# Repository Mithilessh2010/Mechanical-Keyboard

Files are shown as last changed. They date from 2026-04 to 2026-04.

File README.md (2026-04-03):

# Transparent Keyboard

This is a custom mechanical keyboard with a fully clear acrylic case and transparent keycaps.  
The goal of this project was to build a simple keyboard that shows all of the internal parts, lighting, and wiring.





---

## About

This keyboard is designed to be easy to see through and easy to understand.  
Every major part is visible, including the PCB, LEDs, switches, and wiring.  
It uses QMK firmware and a Teensy microcontroller.

---

## Firmware

This keyboard uses QMK firmware.

**Flashing steps**

1. Download QMK Toolbox.
2. Plug the Teensy 2.0 into your computer.
3. Press the boot button on the Teensy.
4. Flash the provided `.hex` firmware file using QMK Toolbox.

---

## Bill of Materials (BOM)

| Item | Price | Quantity | Purpose | Link |
|---|---|---|---|---|
| KTT Kang White V3 Switches | $24.89 | 1 pack (90 pcs) | Mechanical key switches | https://www.aliexpress.us/item/3256807301426125.html |
| WS2812B LED Strip 5V (2m) | $5.16 | 1 strip | RGB backlighting | https://www.aliexpress.us/item/3256804103077154.html |
| Teensy 2.0 | $9.18 | 1 | Microcontroller | https://www.aliexpress.us/item/3256803067426595.html |
| USB Adapter 20cm V8F-V3ST | $2.24 | 1 | Internal USB cable | https://www.aliexpress.us/item/3256805661411472.html |
| Transparent Keycaps | $18.82 | 1 set | Keycaps | https://www.aliexpress.us/item/3256809158263730.html |
| 1/8 in Acrylic Sheet | $15.00 | 1 sheet | Case and plates | Makerspace |
| M2 Screws 4mm | $2.24 | 1 pack | Mounting hardware | https://www.aliexpress.us/item/3256806812715286.html |
| M3 Screws | $0.00 | Owned | Case assembly | Already owned |
| Custom PCBs (JLCPCB) | $33.74 | 5 boards | Keyboard PCB | JLCPCB |
| Keyboard Diodes | $2.38 | 2 packs | Switch matrix diodes | https://www.aliexpress.us/item/3256806058794623.html |
| Gateron V2 Stabilizers | $10.00 | 1 kit | Stabilizers for larger keys | https://mechanicalkeyboards.com/products/gateron-v2-stabilizers-plate-mount-clip-in-tkl-kit |

**Estimated total (before tax and shipping): $121.32**

---

## Notes

This project was made for learning and for fun.  
Feel free to reuse or modify anything in this repository for your own keyboard builds.

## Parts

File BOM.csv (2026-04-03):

Item | Price (USD) | Quantity | Use | Link
KTT Kang White V3 Switches | 24.89 | 1 pack (90 pcs) | Mechanical key switches | https://www.aliexpress.us/item/3256807301426125.html
WS2812B LED Strip 5V 2m 30 LEDs | 5.16 | 1 strip (2m) | Keyboard backlighting | https://www.aliexpress.us/item/3256804103077154.html
Teensy 2.0 Microcontroller | 9.18 | 1 | Keyboard MCU | https://www.aliexpress.us/item/3256803067426595.html
USB Adapter 20cm V8F-V3ST | 2.24 | 1 | USB connection adapter | https://www.aliexpress.us/item/3256805661411472.html
Transparent Keycaps Set | 18.82 | 1 set | Keycaps | https://www.aliexpress.us/item/3256809158263730.html
1/8 in Acrylic Sheet | 15.00 | 1 sheet | Keyboard plate and backplate | Makerspace purchase
M2 Screws 4mm | 2.24 | 1 pack | Mount PCB to case | https://www.aliexpress.us/item/3256806812715286.html
M3 Screws | 0.00 | Owned | General assembly | Already owned
Custom PCBs (JLCPCB) | 33.74 | 5 boards | Keyboard PCB fabrication | JLCPCB
Keyboard Diodes | 2.38 | 2 packs | Switch matrix diodes | https://www.aliexpress.us/item/3256806058794623.html
Gateron V2 Stabilizers Kit | 10.00 | 1 kit | Stabilize larger keys | https://mechanicalkeyboards.com/products/gateron-v2-stabilizers-plate-mount-clip-in-tkl-kit
TOTAL (No tax/shipping) | 123.65
FINAL TOTAL | 121.32

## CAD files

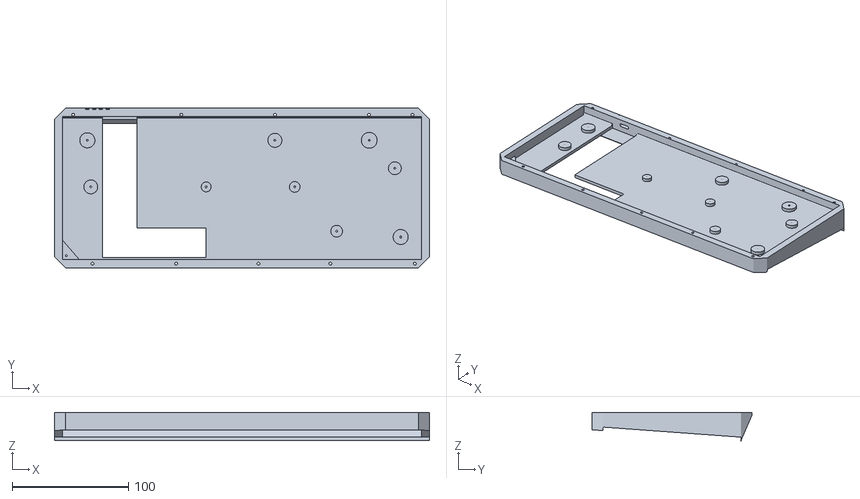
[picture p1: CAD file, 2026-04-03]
Cad files/Bottom whole.stl
321.9 x 137.2 x 24.3

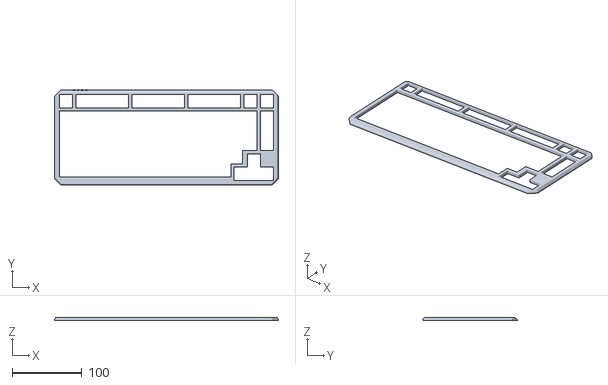
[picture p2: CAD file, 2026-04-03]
Cad files/top whole.stl
321.9 x 137.2 x 4.90

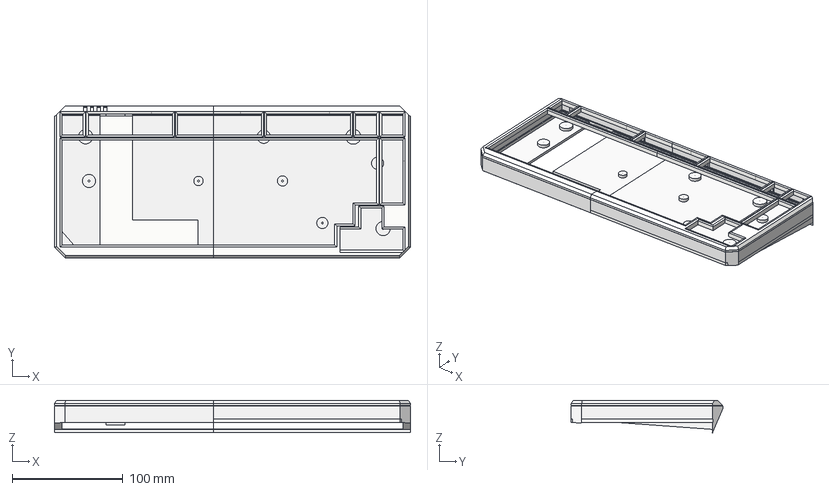
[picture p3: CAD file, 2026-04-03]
Cad files/Transparent Keyboard.step
321.9 x 137.2 x 29.3 mm

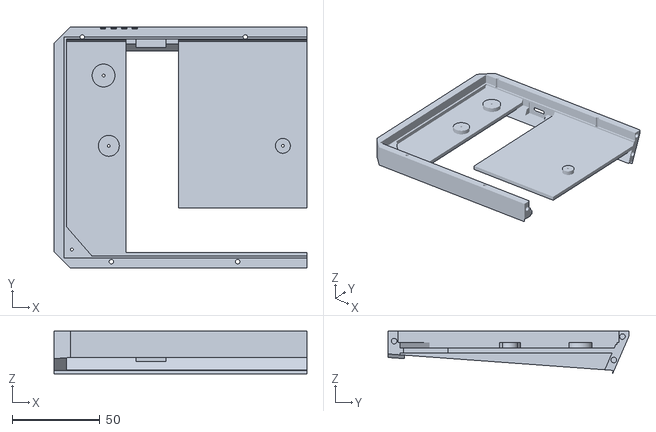
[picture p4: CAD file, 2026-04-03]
Cad files/Left bottom.stl
143.9 x 137.2 x 24.3

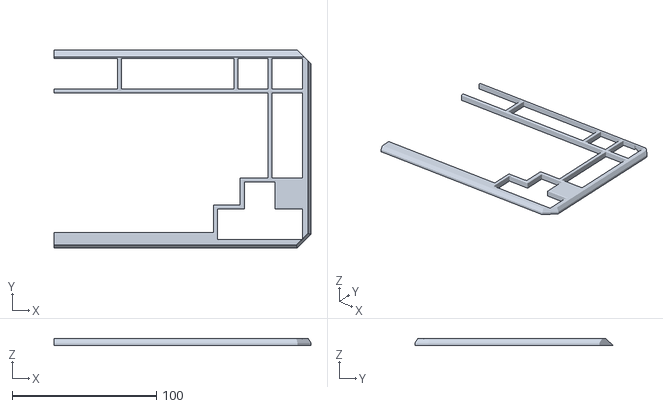
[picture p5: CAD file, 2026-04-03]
Cad files/Right top.stl
178.0 x 137.2 x 4.90

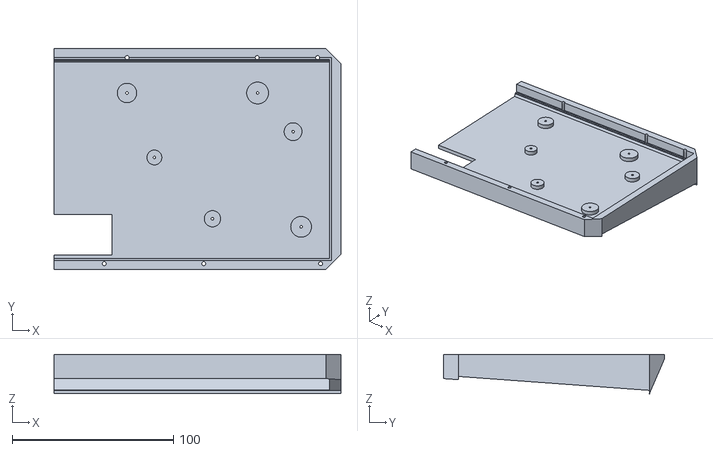
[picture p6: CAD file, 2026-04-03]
Cad files/Right bottom.stl
178.0 x 137.2 x 24.3

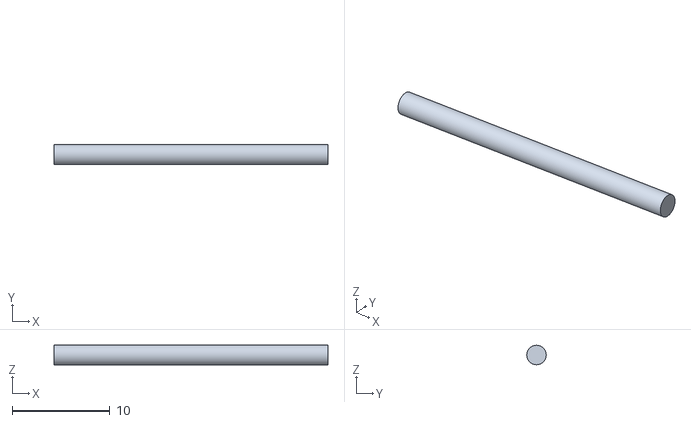
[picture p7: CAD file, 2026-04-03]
Cad files/pin.stl
28.0 x 2.00 x 2.00

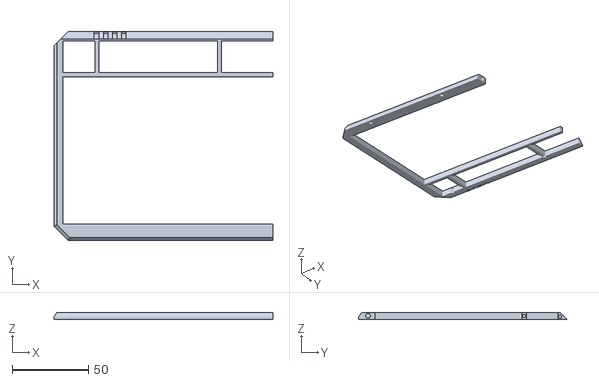
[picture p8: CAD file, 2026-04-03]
Cad files/Left top.stl
143.9 x 137.2 x 4.90

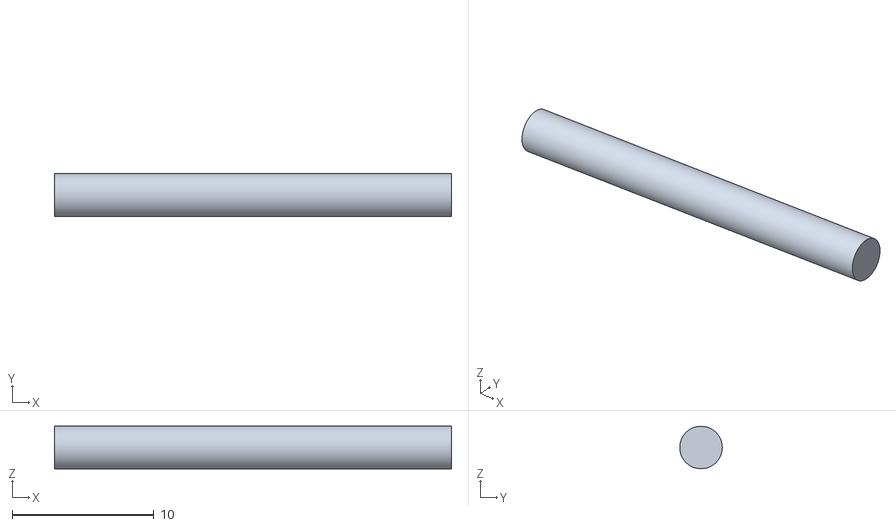
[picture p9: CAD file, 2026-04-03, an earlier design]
Cad files/pin (2).stl
28.0 x 3.00 x 3.00

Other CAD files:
Cad files/main base.stl
Cad files/Top Plate.stl
Cad files/pin (3).stl
Cad files/pin (4).stl
Cad files/pin (5).stl
Cad files/pin (1).stl

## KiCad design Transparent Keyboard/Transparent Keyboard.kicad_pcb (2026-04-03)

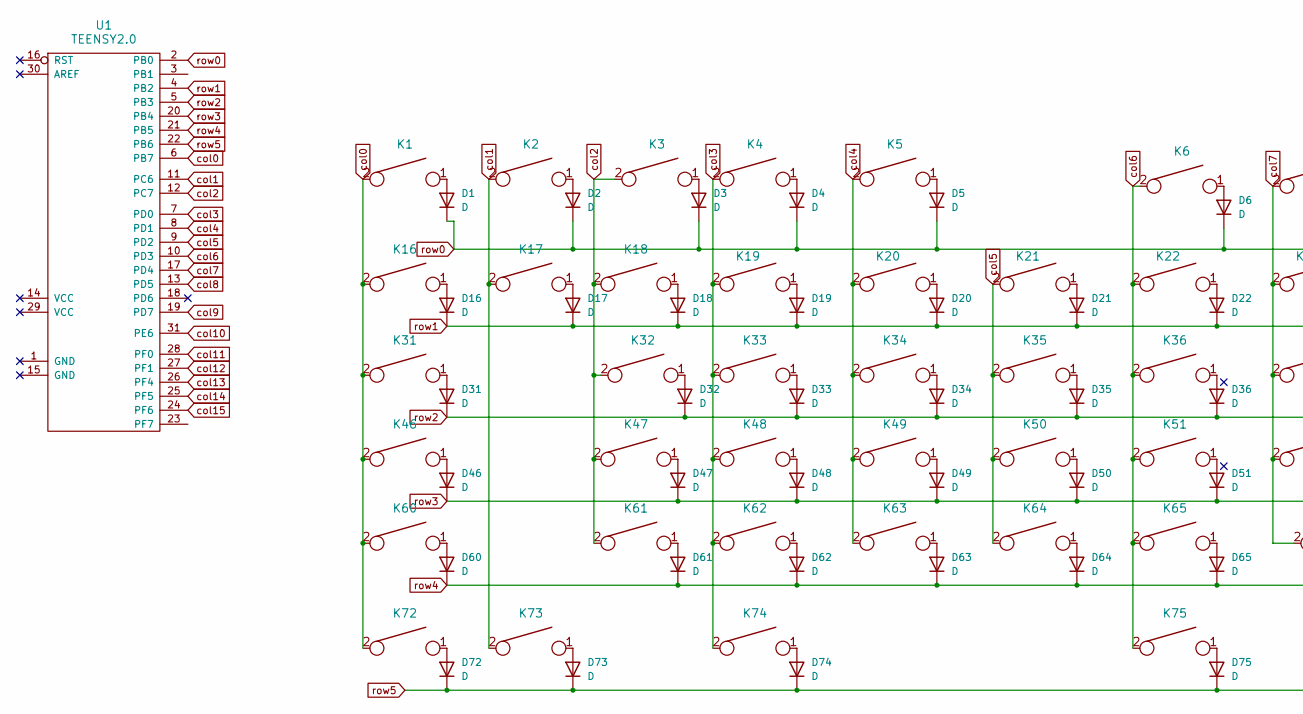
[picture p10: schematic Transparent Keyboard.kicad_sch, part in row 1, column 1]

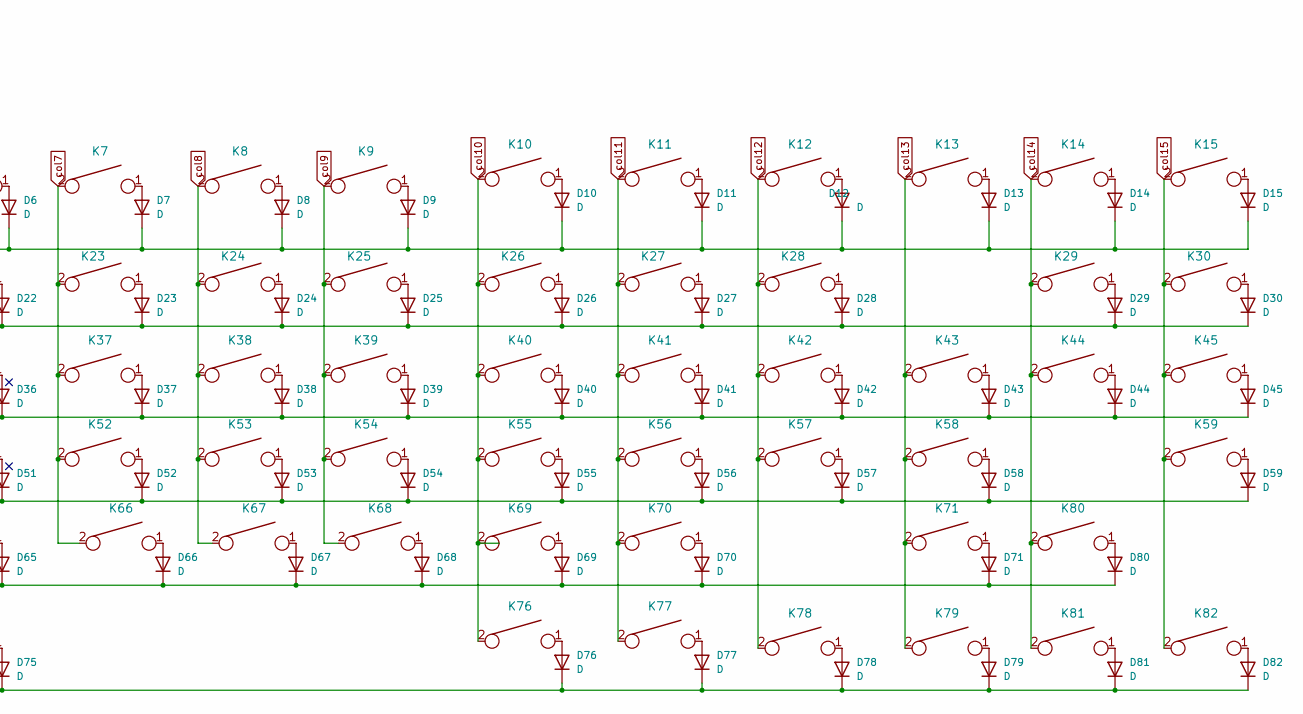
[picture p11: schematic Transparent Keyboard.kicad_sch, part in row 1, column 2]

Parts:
D1, D2, D3, D4, D5, D6, D7, D8, D9, D10, D11, D12, D13, D14, D15, D16, D17, D18, D19, D20, D21, D22, D23, D24, D25, D26, D27, D28, D29, D30, D31, D32, D33, D34, D35, D36, D37, D38, D39, D40, D41, D42, D43, D44, D45, D46, D47, D48, D49, D50, D51, D52, D53, D54, D55, D56, D57, D58, D59, D60, D61, D62, D63, D64, D65, D66, D67, D68, D69, D70, D71, D72, D73, D74, D75, D76, D77, D78, D79, D80, D81, D82: D; D_SOD123_axial
K1, K2, K3, K4, K5, K6, K7, K8, K9, K10, K11, K12, K13, K14, K15, K16, K17, K18, K19, K20, K21, K22, K23, K24, K25, K26, K27, K28, K30, K32, K33, K34, K35, K36, K37, K38, K39, K40, K41, K42, K43, K45, K47, K48, K49, K50, K51, K52, K53, K54, K55, K56, K57, K59, K61, K62, K63, K64, K65, K66, K67, K68, K69, K70, K71, K72, K73, K74, K75, K76, K77, K78, K79, K80, K81, K82: KEYSW; Mx_Alps_100
K29: KEYSW; Mx_Alps_200
K31, K44: KEYSW; Mx_Alps_150
K46: KEYSW; Mx_Alps_175
K58, K60: KEYSW; Mx_Alps_225
U1: TEENSY2.0; Teensy_20

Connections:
unnamed: D1.2 (A), K1.1
unnamed: D2.2 (A), K2.1
unnamed: D3.2 (A), K3.1
unnamed: D4.2 (A), K4.1
unnamed: D5.2 (A), K5.1
unnamed: D6.2 (A), K6.1
unnamed: D7.2 (A), K7.1
unnamed: D8.2 (A), K8.1
unnamed: D9.2 (A), K9.1
unnamed: D10.2 (A), K10.1
unnamed: D11.2 (A), K11.1
unnamed: D12.2 (A), K12.1
unnamed: D13.2 (A), K13.1
unnamed: D14.2 (A), K14.1
unnamed: D15.2 (A), K15.1
unnamed: D16.2 (A), K16.1
unnamed: D17.2 (A), K17.1
unnamed: D18.2 (A), K18.1
unnamed: D19.2 (A), K19.1
unnamed: D20.2 (A), K20.1
unnamed: D21.2 (A), K21.1
unnamed: D22.2 (A), K22.1
unnamed: D23.2 (A), K23.1
unnamed: D24.2 (A), K24.1
unnamed: D25.2 (A), K25.1
unnamed: D26.2 (A), K26.1
unnamed: D27.2 (A), K27.1
unnamed: D28.2 (A), K28.1
unnamed: D29.2 (A), K29.1
unnamed: D30.2 (A), K30.1
unnamed: D31.2 (A), K31.1
unnamed: D32.2 (A), K32.1
unnamed: D33.2 (A), K33.1
unnamed: D34.2 (A), K34.1
unnamed: D35.2 (A), K35.1
unnamed: D36.2 (A), K36.1
unnamed: D37.2 (A), K37.1
unnamed: D38.2 (A), K38.1
unnamed: D39.2 (A), K39.1
unnamed: D40.2 (A), K40.1
unnamed: D41.2 (A), K41.1
unnamed: D42.2 (A), K42.1
unnamed: D43.2 (A), K43.1
unnamed: D44.2 (A), K44.1
unnamed: D45.2 (A), K45.1
unnamed: D46.2 (A), K46.1
unnamed: D47.2 (A), K47.1
unnamed: D48.2 (A), K48.1
unnamed: D49.2 (A), K49.1
unnamed: D50.2 (A), K50.1
unnamed: D51.2 (A), K51.1
unnamed: D52.2 (A), K52.1
unnamed: D53.2 (A), K53.1
unnamed: D54.2 (A), K54.1
unnamed: D55.2 (A), K55.1
unnamed: D56.2 (A), K56.1
unnamed: D57.2 (A), K57.1
unnamed: D58.2 (A), K58.1
unnamed: D59.2 (A), K59.1
unnamed: D60.2 (A), K60.1
unnamed: D61.2 (A), K61.1
unnamed: D62.2 (A), K62.1
unnamed: D63.2 (A), K63.1
unnamed: D64.2 (A), K64.1
unnamed: D65.2 (A), K65.1
unnamed: D66.2 (A), K66.1
unnamed: D67.2 (A), K67.1
unnamed: D68.2 (A), K68.1
unnamed: D69.2 (A), K69.1
unnamed: D70.2 (A), K70.1
unnamed: D71.2 (A), K71.1
unnamed: D72.2 (A), K72.1
unnamed: D73.2 (A), K73.1
unnamed: D74.2 (A), K74.1
unnamed: D75.2 (A), K75.1
unnamed: D76.2 (A), K76.1
unnamed: D77.2 (A), K77.1
unnamed: D78.2 (A), K78.1
unnamed: D79.2 (A), K79.1
unnamed: D80.2 (A), K80.1
unnamed: D81.2 (A), K81.1
unnamed: D82.2 (A), K82.1
col0: K1.2, K16.2, K31.2, K46.2, K60.2, K72.2, U1.6 (PB7)
col1: K2.2, K17.2, K73.2, U1.11 (PC6)
col2: K3.2, K18.2, K32.2, K47.2, K61.2, U1.12 (PC7)
col3: K4.2, K19.2, K33.2, K48.2, K62.2, K74.2, U1.7 (PD0)
col4: K5.2, K20.2, K34.2, K49.2, K63.2, U1.8 (PD1)
col5: K21.2, K35.2, K50.2, K64.2, U1.9 (PD2)
col6: K6.2, K22.2, K36.2, K51.2, K65.2, K75.2, U1.10 (PD3)
col7: K7.2, K23.2, K37.2, K52.2, K66.2, U1.17 (PD4)
col8: K8.2, K24.2, K38.2, K53.2, K67.2, U1.13 (PD5)
col9: K9.2, K25.2, K39.2, K54.2, K68.2, U1.19 (PD7)
col10: K10.2, K26.2, K40.2, K55.2, K69.2, K76.2, U1.31 (PE6)
col11: K11.2, K27.2, K41.2, K56.2, K70.2, K77.2, U1.28 (PF0)
col12: K12.2, K28.2, K42.2, K57.2, K78.2, U1.27 (PF1)
col13: K13.2, K43.2, K58.2, K71.2, K79.2, U1.26 (PF4)
col14: K14.2, K29.2, K44.2, K80.2, K81.2, U1.25 (PF5)
col15: K15.2, K30.2, K45.2, K59.2, K82.2, U1.24 (PF6)
row0: D1.1 (K), D2.1 (K), D3.1 (K), D4.1 (K), D5.1 (K), D6.1 (K), D7.1 (K), D8.1 (K), D9.1 (K), D10.1 (K), D11.1 (K), D12.1 (K), D13.1 (K), D14.1 (K), D15.1 (K), U1.2 (PB0)
row1: D16.1 (K), D17.1 (K), D18.1 (K), D19.1 (K), D20.1 (K), D21.1 (K), D22.1 (K), D23.1 (K), D24.1 (K), D25.1 (K), D26.1 (K), D27.1 (K), D28.1 (K), D29.1 (K), D30.1 (K), U1.4 (PB2)
row2: D31.1 (K), D32.1 (K), D33.1 (K), D34.1 (K), D35.1 (K), D36.1 (K), D37.1 (K), D38.1 (K), D39.1 (K), D40.1 (K), D41.1 (K), D42.1 (K), D43.1 (K), D44.1 (K), D45.1 (K), U1.5 (PB3)
row3: D46.1 (K), D47.1 (K), D48.1 (K), D49.1 (K), D50.1 (K), D51.1 (K), D52.1 (K), D53.1 (K), D54.1 (K), D55.1 (K), D56.1 (K), D57.1 (K), D58.1 (K), D59.1 (K), U1.20 (PB4)
row4: D60.1 (K), D61.1 (K), D62.1 (K), D63.1 (K), D64.1 (K), D65.1 (K), D66.1 (K), D67.1 (K), D68.1 (K), D69.1 (K), D70.1 (K), D71.1 (K), D80.1 (K), U1.21 (PB5)
row5: D72.1 (K), D73.1 (K), D74.1 (K), D75.1 (K), D76.1 (K), D77.1 (K), D78.1 (K), D79.1 (K), D81.1 (K), D82.1 (K), U1.22 (PB6)

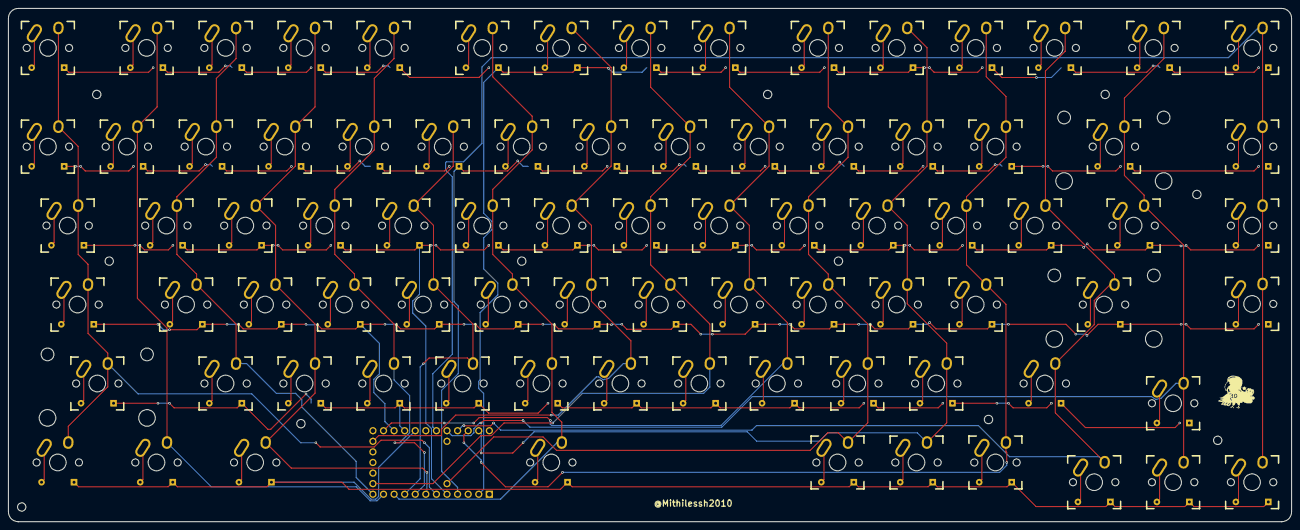
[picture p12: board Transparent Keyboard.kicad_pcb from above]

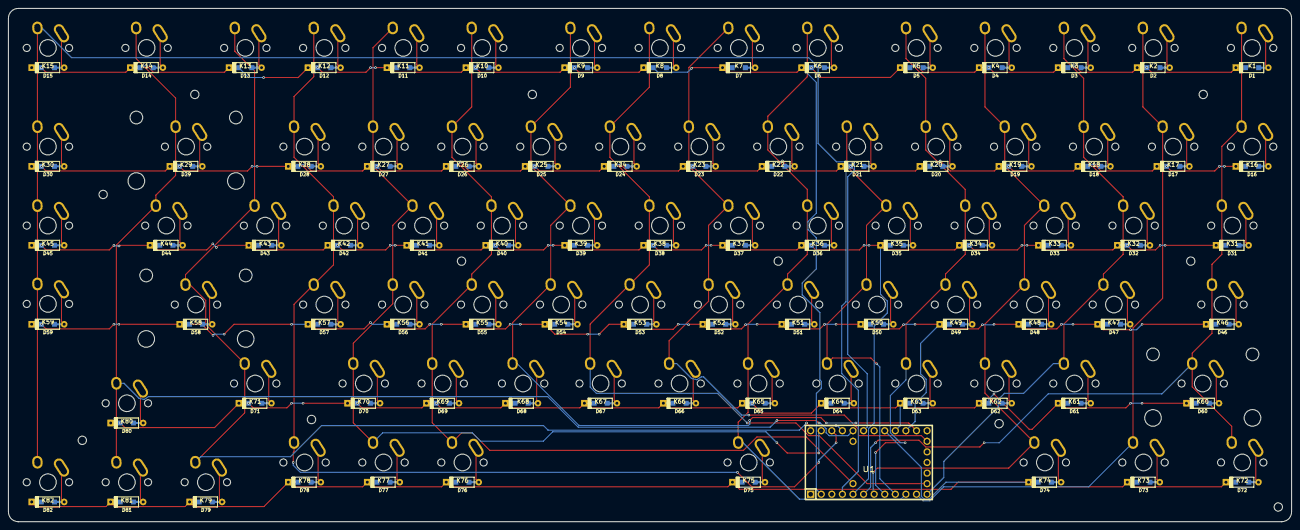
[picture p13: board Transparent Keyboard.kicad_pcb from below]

Board: 2 copper layers, 307.9 x 123.2 mm, 165 parts (83 on the bottom side), 104 nets.

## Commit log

2026-03-18 Add README for mechanical keyboard project
    Added detailed information about the mechanical keyboard, including features, PCB, case design, firmware requirements, build commands, flashing instructions, and a parts list.
2026-04-03 Fixed everything updated
    [750-THR-Earthtyper.step, BOM.csv, Bottom whole.stl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]
